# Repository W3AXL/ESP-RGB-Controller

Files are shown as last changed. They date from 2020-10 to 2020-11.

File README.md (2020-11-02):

# ESP-RGB-Controller
Tiny ESP8266-based RGB LED controller

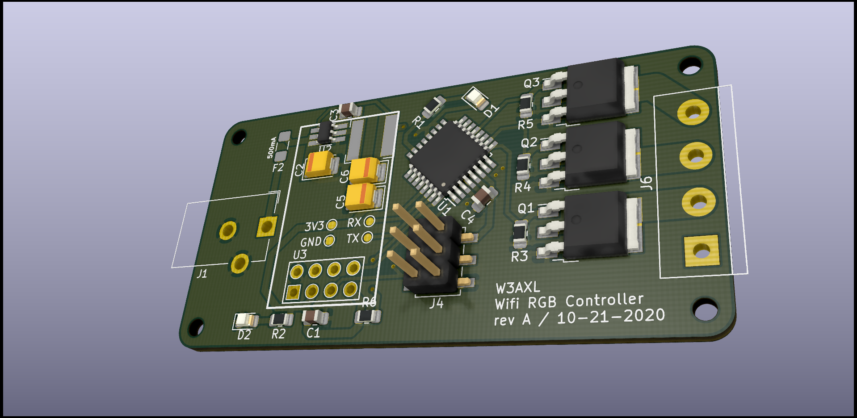
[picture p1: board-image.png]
Image of the board


## Board Hardware
*Located in the root directory*

Included is the kicad project for the PCB. It's very simple and requires minimal parts. An included BOM.txt gives part numbers used for my assemblies. However, feel free to substitute parts as you see fit.

## Board Firmware
*Located in the SW-Arduino Directory*

The MCU is an AtMega328P in 32-TQFP package. **You will need an ISP tool to flash the firmware, such as a [USBTinyISP](https://learn.adafruit.com/usbtinyisp) or an [Arduino flashed as an ISP](https://www.arduino.cc/en/Tutorial/BuiltInExamples/ArduinoISP).**

The firmware was designed to run on the [Minicore Arduino platform](https://github.com/MCUdude/MiniCore). You will need to add this to your boards manager and install it in your Arduino IDE. The following settings are used to compile and flash the firmware:

* Board: AtMega328
* Clock: Internal 8MHz
* BOD: 2.7V
* EEPROM: EEPROM retained
* Compiler LTO: LTO Disabled
* Variant: 328P/PA
* Bootloader: No Bootloader

You will also need the WifiEspAt library for Arduino, and will need to edit the Wifi login credentials to match your wifi network. Otherwise, it should be plug and play with up-to-date ESP-01 modules.

**Note: You will need to update your ESP-01 modules to AT version 2.1 or greater. See [the following page on firmware versions from the WifiESPAt library](https://github.com/jandrassy/WiFiEspAT#at-firmware-versions)**

A minor overview of the features of this firmware:
* Recalls last state on power-up, useful if power is interrupted
* Reports the current setting in a small webpage when the GET request is recieved, useful for status checking

## Control the lights!
### GET Requests
The simplest method of control is through your browser, with a simple HTTP GET request like so:
```
http://<ip.address>?rgb=255,255,255
```
This will set all three color channels to full brightness.
### Controller App
*Locategd in SW-TrayTool*

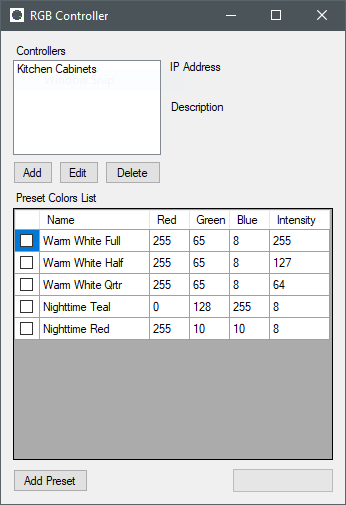
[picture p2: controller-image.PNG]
Image of controller app


You can build the C# Windows Forms app for a slightly more robust control system. The tool includes provisions for multiple controllers and presets, as well as a tray icon for controlling lights in a nice clean way.

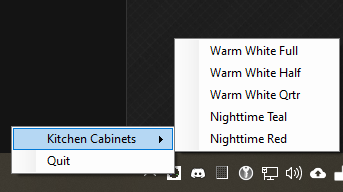
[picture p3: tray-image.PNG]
Image of tray icon


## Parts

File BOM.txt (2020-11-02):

Qty   | Desc                          | Ref           | P/N
-------------------------------------------------------------------------
2       22uF Tant Cap, SMD 1411	        C5,C6           TAJB226K020RNJ‎
1       10uF Tant Cap, SMD 1411         C2              ‎TAJB106K020RNJ‎
1       3.3V Buck Regulator, TSOT26     U2              AP63203WU-7
1       ATMega328P-AU TQFP-32           U1              ‎ATMEGA328P-AU
1       2mm x 5.5mm DC Barrel Jack      J1              PJ-102AH
3       0.1uF Ceramic Cap, SMD 0805     C1,C3,C4        CL21B104KACNNNC‎
1       3.9uH Inductor SMD 6x6mm        L1              ‎ASPI-0628-3R9M-T1
1       Blue LED SMD 0805               STAT            150080BS75000‎
1       Red LED SMD 0805                PWR             150080RS75000
1       500mA Fuse SMD 1206             F2              C1F 500
1       4A Fuse SMD 1206                F1              C1F 4
1       02x03 0.1" ISP Header SMD       J4              10129383-906001ALF
1       4-Pos Screw Terminal 0.2" THT   J6              Eb21A-04-D
3       N-CH MOSFET 10A 30V SMD TO252   Q1,Q2,Q3        ‎DMG4800LK3-13
2       1kOhm Resistor SMD 0805	        R1,R2           RNCP0805FTD1K00‎
4       10kOhm Resistor SMD 0805        R3,R4,R5,R6     ‎RNCP0805FTD10K0
1       02x04 0.1" ESP-01 Socket        U3              ‎RS2-08-G‎

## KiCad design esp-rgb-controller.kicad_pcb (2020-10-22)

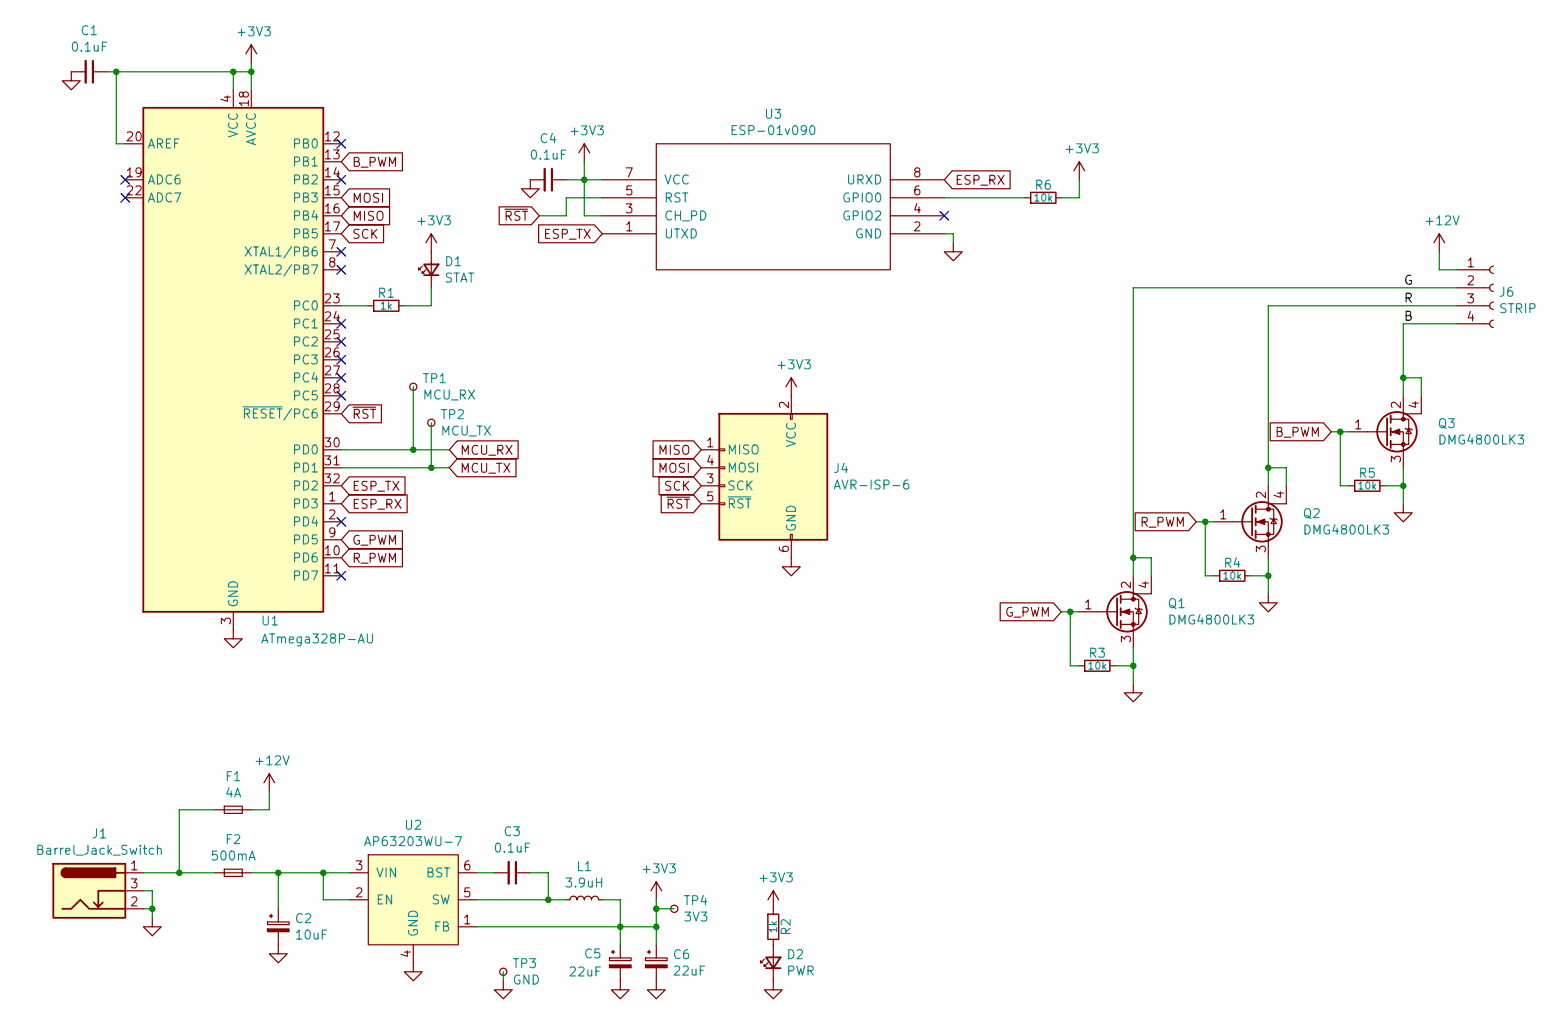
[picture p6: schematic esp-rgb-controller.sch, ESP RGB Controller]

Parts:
C1, C3, C4: 0.1uF; C_0805_2012Metric_Pad1.15x1.40mm_HandSolder
C2: 10uF; CP_EIA-3528-15_AVX-H_Pad1.50x2.35mm_HandSolder
C5, C6: 22uF; CP_EIA-3528-15_AVX-H_Pad1.50x2.35mm_HandSolder
D1: STAT; LED_0805_2012Metric_Pad1.15x1.40mm_HandSolder
D2: PWR; LED_0805_2012Metric_Pad1.15x1.40mm_HandSolder
F1: 4A; Fuse_1206_3216Metric_Pad1.42x1.75mm_HandSolder
F2: 500mA; Fuse_1206_3216Metric_Pad1.42x1.75mm_HandSolder
J1: Barrel_Jack_Switch; BarrelJack_CUI_PJ-102AH_Horizontal
J4: AVR-ISP-6; PinHeader_2x03_P2.54mm_Vertical_SMD
J6: STRIP; TerminalBlock_bornier-4_P5.08mm
L1: 3.9uH; L_Bourns-SRN6028
Q1, Q2, Q3: DMG4800LK3; TO-252-3_TabPin4
R1, R2: 1k; R_0805_2012Metric_Pad1.15x1.40mm_HandSolder
R3, R4, R5, R6: 10k; R_0805_2012Metric_Pad1.15x1.40mm_HandSolder
TP1: MCU_RX; TestPoint_Pad_D1.0mm
TP2: MCU_TX; TestPoint_Pad_D1.0mm
TP3: GND; TestPoint_Pad_D1.0mm
TP4: 3V3; TestPoint_Pad_D1.0mm
U1: ATmega328P-AU; TQFP-32_7x7mm_P0.8mm
U2: AP63203WU-7; TSOT-23-6_HandSoldering
U3: ESP-01v090; ESP-01

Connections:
+3V3: C1.1, C4.1, C5.1, C6.1, D1.2 (A), J4.2 (VCC), L1.2, R2.1, R6.2, TP4.1, U1.4 (VCC), U1.6 (VCC), U1.18 (AVCC), U1.20 (AREF), U2.1 (FB), U3.3 (CH_PD), U3.7 (VCC)
+12V: F1.2, J6.1
/B: J6.4, Q3.2 (D), Q3.4 (D)
/G: J6.2, Q1.2 (D), Q1.4 (D)
/R: J6.3, Q2.2 (D), Q2.4 (D)
B_PWM: Q3.1 (G), R5.1, U1.13 (PB1)
ESP_RX: U1.1 (PD3), U3.8 (URXD)
ESP_TX: U1.32 (PD2), U3.1 (UTXD)
GND: C1.2, C2.2, C4.2, C5.2, C6.2, D2.1 (K), J1.2, J1.3, J4.6 (GND), Q1.3 (S), Q2.3 (S), Q3.3 (S), R3.2, R4.2, R5.2, TP3.1, U1.3 (GND), U1.5 (GND), U1.21 (GND), U2.4 (GND), U3.2 (GND)
G_PWM: Q1.1 (G), R3.1, U1.9 (PD5)
MCU_RX: TP1.1, U1.30 (PD0)
MCU_TX: TP2.1, U1.31 (PD1)
MISO: J4.1 (MISO), U1.16 (PB4)
MOSI: J4.4 (MOSI), U1.15 (PB3)
unnamed: C2.1, F2.2, U2.2 (EN), U2.3 (VIN)
unnamed: C3.1, L1.1, U2.5 (SW)
unnamed: C3.2, U2.6 (BST)
unnamed: D1.1 (K), R1.2
unnamed: D2.2 (A), R2.2
unnamed: F1.1, F2.1, J1.1
unnamed: R1.1, U1.23 (PC0)
unnamed: R6.1, U3.6 (GPIO0)
R_PWM: Q2.1 (G), R4.1, U1.10 (PD6)
SCK: J4.3 (SCK), U1.17 (PB5)
~RST: J4.5 (~RST), U1.29 (~RESET~/PC6), U3.5 (RST)

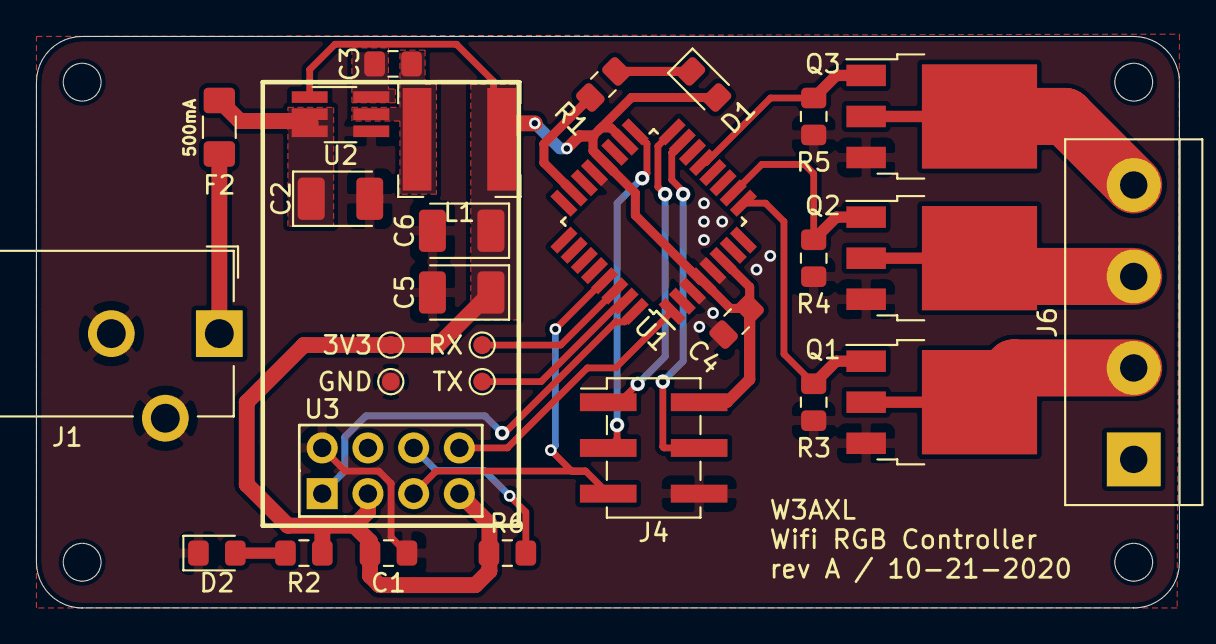
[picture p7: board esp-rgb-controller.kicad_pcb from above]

Board: 2 copper layers, 63.5 x 31.8 mm, 30 parts (1 on the bottom side), 25 nets.

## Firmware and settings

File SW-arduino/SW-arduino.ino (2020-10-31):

#include <NeoSWSerial.h>
#include <WiFiEspAT.h>
#include <EEPROM.h>

#define RPIN    PD6
#define GPIN    PD5
#define BPIN    PB1
#define STATPIN PC0

#define RXPIN   PD2
#define TXPIN   PD3

#define COL_WARM_WHITE_R 255
#define COL_WARM_WHITE_G 75
#define COL_WARM_WHITE_B 15

#define EE_R_ADDR           11
#define EE_G_ADDR           12
#define EE_B_ADDR           13
#define EE_BR_ADDR          15
#define EE_MODE_ADDR        21
#define EE_FIRSTBOOT_ADDR   31

const char ssid[] = "308 (Formerly Bobby T's)";
const char pass[] = "BrothersisBetter";

#define HOSTNAME    "espRGB_kitchen"

NeoSWSerial esp(RXPIN,TXPIN);
WiFiServer server(80);

// ESP variables
int espStatus;
int srvReqCnt = 0;

// Serial Comm Variables
const byte recvSize = 32;
char recvBuf[recvSize];
bool recvMsg = false;

/**
 * @brief clears the terminal window
 */
void clearTerm() {
    Serial.write(27); // ESC
    Serial.print("[2J"); // clear screen
    Serial.write(27); // ESC
    Serial.print("[H"); // cursor to home
}

/** 
 * @brief initializes OSC1 for PWM on pin PB1
 */
void pwmInitOSC1A() {
    // Init pin PB1 as output
    DDRB |= B00000010;
    // OSC1 PWM Init
    TCCR1A |= (1<<COM1A1)|(1<<WGM10);    // OCR1A in normal mode, phase-corrected PWM
    TCCR1B |= (1<<CS11);                 // CLK/8 prescaler
}

/**
 * @brief sets output to an RGB value
 * @param R red value (0-255)
 * @param G green value (0-255)
 * @param B blue value (0-255)
 * @param save whether to save settings to EEPROM
 */
void setRGB(char R, char G, char B, bool save) {
    Serial.print("Setting RGB:");
    Serial.print(R);
    Serial.print(" ");
    Serial.print(G);
    Serial.print(" ");
    Serial.println(B);
    // set our PWM outputs
    analogWrite(RPIN,R);
    analogWrite(GPIN,G);
    OCR1A = B;
    // save our values to EEPROM if desired
    if (save) {
        EEPROM.write(EE_MODE_ADDR, 0);  // mode 0, RGB
        EEPROM.write(EE_R_ADDR, R);     // R byte
        EEPROM.write(EE_G_ADDR, G);     // G byte
        EEPROM.write(EE_B_ADDR, B);     // B byte
    }
}

/**
 * @brief sets output color to a warm white
 * @param brightness scale factor (0-1) for brightness of output
 * @param save whether to save settings to EEPROM
 */
void setWarm(char brightness, bool save) {
    float bFloat = (float)brightness / 255.0;
    setRGB( COL_WARM_WHITE_R * bFloat,
            COL_WARM_WHITE_G * bFloat,
            COL_WARM_WHITE_B * bFloat,
            false);
    // save values to EEPROM
    if (save) {
        EEPROM.write(EE_MODE_ADDR, 1);          // mode 1, warm white
        EEPROM.write(EE_B_ADDR, brightness);    // brightness byte
    }
}

void startupColor() {
    // read what mode we're in
    char mode = EEPROM.read(EE_MODE_ADDR);
    switch (mode) {
        case 0: { // RGB mode
            Serial.println("starting in RGB mode");
            char EE_R = EEPROM.read(EE_R_ADDR);
            char EE_G = EEPROM.read(EE_G_ADDR);
            char EE_B = EEPROM.read(EE_B_ADDR);
            setRGB(EE_R, EE_G, EE_B, false);
            break;
        }
        case 1: { // warm white mode
            Serial.println("starting in warm white mode");
            char bright = EEPROM.read(EE_BR_ADDR);
            setWarm(bright, false);
            break;
        }
    }
}

/**
 * @brief processes serial commands from the PC
 */
void recvSerialCmd() {
    // wait a second for any more data
    delay(5);
    statLed(true);
    const char eol = '\n';
    char rc;
    int idx = 0;
    while (Serial.available() > 0 && !recvMsg) {
        rc = Serial.read();
        if (rc != eol) {
            recvBuf[idx] = rc;
            idx++;
            if (idx >= recvSize) {
                idx = recvSize - 1;
            }
        } else {
            recvBuf[idx] = '\0';
            idx = 0;
            recvMsg = true;
        }
    }
}

/**
 * @brief processes recieved serial data from PC
 */
void procSerialCmd() {
    if (recvMsg) {
        Serial.print(" PC>>MCU: ");
        Serial.println(recvBuf);
        statLed(false);
        recvMsg = false;
        // actual command processing
    }
}

/**
 * @brief turns the status LED on or off
 * @param state LED state
 */
void statLed(bool state) {
    if (state) {
        PORTC = PORTC & ~(1 << PINC0);
    }
    else {
        PORTC = PORTC | (1 << PINC0);
    }
}

/**
 * @brief error LED loop function for fatal errors
 * @param flashes number of LED flashes
 * @param period delay between flashes
 */
void errorLoop(int flashes, int period) {
    while(1) {
        for (int i=0;i<flashes;i++) {
            delay(period);
            statLed(true);
            delay(period);
            statLed(false);
        }
        delay(1000);
    }
}

/**
 * @brief processes a GET string
 * @param getStr string that contains the GET request line
 * @cite https://stackoverflow.com/questions/24696113/how-to-find-text-between-two-strings-in-c
 */
void recvGET(String getStr) {
    // valid characters for terminating get parameters
    const char *endPattern1 = " ";  // end of request
    const char *endPattern2 = "&";  // next parameter
    // convert our String to a c character array
    char lineBuf[64];
    getStr.toCharArray(lineBuf,64);
    Serial.print("Processing GET request: ");
    Serial.println(lineBuf);

    // check if we have an RGB command in the string
    if (strstr(lineBuf, "rgb=") != NULL) {
        Serial.print("found RGB command: ");
        // isolate the RGB command (this is from the stackexchange article)
        const char *startPattern = "rgb=";
        char *target = NULL;
        char *start, *end;
        // find the beginning
        if (start = strstr(lineBuf,startPattern)) {
            start += strlen(startPattern);
            // testing end pattern 1
            if (end = strstr( start, endPattern1)) {
                target = (char*)malloc(end-start+1);
                memcpy(target, start, end-start);
                target[end-start] = '\0';
            // testing end pattern 2
            } else if (end = strstr (start, endPattern2)) {
                target = (char*)malloc(end-start+1);
                memcpy(target, start, end-start);
                target[end-start] = '\0';
            }
        }
        // if we found a valid rgb string, process it
        if (target) {
            // extract the three RGB values
            char *delim;
            // extract R
            delim = strtok(target,",");
            int getR = atoi(delim);
            Serial.print("R:");
            Serial.print(getR);
            // extract G
            delim = strtok(NULL,",");
            int getG = atoi(delim);
            Serial.print(" G:");
            Serial.print(getG);
            // extract B
            delim = strtok(NULL,",");
            int getB = atoi(delim);
            Serial.print(" B:");
            Serial.println(getB);
            // cleanup
            free(target);
            // set the new RGB values
            setRGB(getR,getG,getB,true);
        }
    } 
    // if we don't have an RGB string, see if we have a warm white string (RGB takes precedence)
    else if (strstr(lineBuf, "warm=") != NULL) {
        Serial.print("found warm white command: ");
        // isolate the RGB command (this is from the stackexchange article)
        const char *startPattern = "warm=";
        char *target = NULL;
        char *start, *end;
        // find the beginning
        if (start = strstr(lineBuf,startPattern)) {
            start += strlen(startPattern);
            // testing end pattern 1
            if (end = strstr( start, endPattern1)) {
                target = (char*)malloc(end-start+1);
                memcpy(target, start, end-start);
                target[end-start] = '\0';
            // testing end pattern 2
            } else if (end = strstr (start, endPattern2)) {
                target = (char*)malloc(end-start+1);
                memcpy(target, start, end-start);
                target[end-start] = '\0';
            }
        }
        // if we found a valid warm white string, process it
        if (target) {
            // extract the brightness
            char getBright = atoi(target);
            Serial.print("Brightness: ");
            Serial.print(getBright);
            // cleanup
            free(target);
            // set the new RGB values
            setWarm(getBright,true);
        }
    }
}

void setup() { 
    // Start serial
    Serial.begin(19200);
    //clearTerm();
    Serial.println("");
    Serial.println("");
    Serial.println("");
    Serial.println("Starting up");
    // initialize PD5&6
    pinMode(RPIN,OUTPUT);
    pinMode(GPIN,OUTPUT);
    // initialize PC0
    DDRC |= B00000001;
    statLed(false);
    // initialize PB1
    pwmInitOSC1A();
    // start ESP serial
    esp.begin(9600);
    // set output from EEPROM if this isn't the first boot (default EEPROM values are 0xFF)
    char firstBoot = EEPROM.read(EE_FIRSTBOOT_ADDR);
    if (!firstBoot) {
        startupColor();
    } else {
        Serial.println("first boot, initializing EEPROM");
        EEPROM.write(EE_FIRSTBOOT_ADDR,0);  // write a zero
        setRGB(0,0,0,true);
    }
    // initialization done
    Serial.println("Powerup complete");
    delay(1000);
    // connect to esp
    Serial.println("Initiazling ESP");
    WiFi.init(esp);
    if (WiFi.status() == WL_NO_MODULE) {
        Serial.println("can't connect to ESP8266");
        errorLoop(1,250);
    }
    // Set hostname
    WiFi.hostname(HOSTNAME);
    // Connect to WiFI network
    Serial.println("Connecting to WIFI network: " + String(ssid));
    while (espStatus != WL_CONNECTED) {
        espStatus = WiFi.begin(ssid, pass);
    }
    IPAddress ip = WiFi.localIP();
    Serial.print("IP: ");
    Serial.println(ip);
    // Start server
    Serial.println("Starting ESP webserver");
    server.begin();
    // Done with setup
    Serial.println("Entering loop");
}

void loop() {
    // Process serial command first
    if (Serial.available()) {
        recvSerialCmd();
        procSerialCmd();
    }
    // now process server request
    WiFiClient client = server.available();
    if (client) {
        IPAddress ip = client.remoteIP();
        Serial.print("new client ");
        Serial.println(ip);

        while (client.connected()) {
            if (client.available()) {
                String line = client.readStringUntil('\n');
                line.trim();
                //Serial.println(line);
            
                // Process the GET header
                if(line.startsWith("GET")) {
                    // send the request to the GET processor
                    recvGET(line);
                }

                // if you've gotten to the end of the HTTP header (the line is blank),
                // the http request has ended, so you can send a reply
                if (line.length() == 0) {
                    // send a standard http response header
                    client.println("HTTP/1.1 200 OK");
                    client.println("Content-Type: text/html");
                    client.println("Connection: close");  // the connection will be closed after completion of the response
                    //client.println("Refresh: 20");  // refresh the page automatically every 5 sec
                    client.println();
                    client.println("<!DOCTYPE HTML>");
                    client.println("<html>");
                    // get current settings
                    char curMode = EEPROM.read(EE_MODE_ADDR);
                    // mode
                    client.print("Mode: ");
                    client.print(curMode);
                    client.print(" ");
                    switch (curMode) {
                        case 0: {
                            client.print("RGB (");
                            int curR = EEPROM.read(EE_R_ADDR);
                            int curG = EEPROM.read(EE_G_ADDR);
                            int curB = EEPROM.read(EE_B_ADDR);
                            client.print(curR);
                            client.print(",");
                            client.print(curG);
                            client.print(",");
                            client.print(curB);
                            client.print(")");
                            break;
                        }
                        case 1: {
                            client.print("Warm White (");
                            char curBr = EEPROM.read(EE_BR_ADDR);
                            client.print(curBr);
                            client.print(")");
                            break;
                        }
                    }
                    client.print("<br/>");
                    client.println("</html>");
                    client.flush();
                    break;
                }
            }
        }
        // close the connection:
        client.stop();
        Serial.println("client disconnected");
    }
}

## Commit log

2020-10-19 initial schematic work
    [esp-rgb-controller.kicad_pcb, esp-rgb-controller.sch]
2020-10-19 initial PCB work
    [esp-rgb-controller.sch]
2020-10-20 more PCB work
    [esp-rgb-controller.kicad_pcb]
2020-10-21 more schematic + pcb work
    [esp-rgb-controller.kicad_pcb, esp-rgb-controller.sch]
2020-10-22 finished up design, ordered
    [esp-rgb-controller-B_Cu.gbr, esp-rgb-controller-B_Mask.gbr, esp-rgb-controller-B_SilkS.gbr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]
2020-10-31 finished code for arduino
2020-11-02 added board image
2020-11-02 added BOM
